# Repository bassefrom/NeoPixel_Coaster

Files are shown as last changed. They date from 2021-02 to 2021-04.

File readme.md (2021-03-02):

# NeoPixel Coaster
#
# The NeoPixel coaster is a battery driven coaster that light up using NeoPixels. 
# The NeoPixels are driven with an attiny85. 
# The colors of the NeoPixels are temperature dependent and the attiny85 is connected to a thermistor to calculate the appropriate RGB values for.
#
# Programming the attiny85:
#
# Program the Arduino Uno with Arduino as ISP example program
#
# Add support for attiny85 in Arduino IDE:
# Go to preferences in Arduino IDE.
# Add this line to Additional Boards Manager URLs: https://raw.githubusercontent.com/damellis/attiny/ide-1.6.x-boards-manager/package_damellis_attiny_index.json
# Under Tools, select ATtiny25/45/85 board
# Select ATtiny85 as Processor
# Select Internal 8MHz clock
#
# Connect Arduino pin 13 (SCK) to attiny85 pin 7
# Connect Arduino pin 12 (MISO) to attiny85 pin 6
# Connect Arduino pin 11 (MOSI) to attiny85 pin 5
# Connect Arduino pin 10 (RESET) to attiny85 pin 1
# Connect Arduino 5V to attiny85 pin 8
# Connect Arduino GND to attiny85 pin 4
#
# Burn Arduino bootloader to attiny85
# Program the attiny85 from Arduino IDE
#
#
# AVRDUDE programming to be implemented (not supported as of now):
# How to use avrdude for programming HEX-files to the attiny85 using Arduino Uno as ISP:
# Connect the attiny85 in the same way you connect it when programming using the Arduino IDE.
# attiny85 has name t85 in avrdude. Use the following line to verify the attiny85 is connected properly:
# avrdude -c avrisp -b 19200 -p t85 -P COMX -n
# Set 8MHz internal oscillator using these fuse bits: 0xE2 and 0xD9 with the followign line:
# avrdude -c avrisp -b 19200 -p t85 -P COMX -U lfuse:w:0xE2:m -U hfuse:w:0xD9:m
# Program the attiny85 using this line:
# avrdude -P COM1 -b 19200 -c avrisp -p t85 -u -U flash:w:"{HEX-file directory here}\file.hex":i
#
# It can be done using a single line as well:
# avrdude -P COM1 -b 19200 -c avrisp -p t85 -u -U efuse:w:0xFF:m -U lfuse:w:0xE2:m -U hfuse:w:0xD9:m -U flash:w:"{HEX-file directory here}\file.hex":i
#
# Example: avrdude -P COM1 -b 19200 -c avrisp -p t85 -u -U efuse:w:0xFF:m -U lfuse:w:0xE2:m -U hfuse:w:0xD9:m -U flash:w:"C:\Users\Basse\Documents\KiCad\NeoPixel_Coaster\Software\ATTiny85_NeoPixel\ATTiny85_NeoPixel.ino.hex":i

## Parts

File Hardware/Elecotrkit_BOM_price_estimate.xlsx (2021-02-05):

Id | Designator | Package | Quantity | Designation | Supplier and ref | Styckpris | 10st styckpris | Totalt pris | Totalt pris vid 5st | Enhetspris vid 10st
1 | BT1 | LiPo Battery 150mAh | 1 | Battery_Cell | https://www.electrokit.com/produkt/batteri-lipo-3-7v-400mah-2/ | 75 | 67.5 | 75 | 375 | 67.5
2 | J1 | USB_Mini-B_No_Holes | 1 | USB_B_Mini | https://www.electrokit.com/produkt/usb-mini-b-smd/ | 8.24 | 7.42 | 8.24 | 41.2 | 7.42
3 | C1,C2 | C_1206_3216Metric | 2 | 4.7u | https://www.electrokit.com/produkt/kondensator-1206-x7r-4-7uf-%c2%b110-16v/ | 4 | 4 | 8 | 40 | 8
4 | D1 | D_1206_3216Metric | 1 | LED | https://www.electrokit.com/produkt/led-orange-1206-100-mcd-klar/ | 2.45 | 2.21 | 2.45 | 12.25 | 2.21
5 | D2,D3,D4,D5 | WS2812_2020_SMD | 4 | WS2812B | https://www.electrokit.com/produkt/led-smd5050-rgb-adresserbar-sk6812/ | 5.5 | 4.68 | 22 | 110 | 18.72
6 | J2 | PinHeader_2x03_P1.27mm_Vertical_SMD | 1 | Conn_02x03_Odd_Even | https://www.electrokit.com/produkt/stiftlist-1-27mm-2x40p-smd/ or https://www.electrokit.com/produkt/hylslist-1-27mm-2x5p-smd/ | 1.5 | 1.5 | 1.5 | 7.5 | 1.5
7 | R1 | R_1206_3216Metric | 1 | 1k | https://www.electrokit.com/produkt/motstand-1kohm-0-25w-smd-1206/ | 0.35 | 0.35 | 0.35 | 1.75 | 0.35
8 | R2 | R_1206_3216Metric | 1 | 4.7k | https://www.electrokit.com/produkt/motstand-4-7kohm-0-25w-smd-1206/ | 0.35 | 0.35 | 0.35 | 1.75 | 0.35
9 | R3 | R_1206_3216Metric | 1 | 100k | https://www.electrokit.com/produkt/motstand-100kohm-0-25w-smd-1206/ | 0.35 | 0.35 | 0.35 | 1.75 | 0.35
10 | S1 | Skjutomkopplare 2-pol on-on-on pcb | 1 | EG1218 | https://www.electrokit.com/produkt/skjutomkopplare-mini-1-pol-on-on-smd/ | 9 | 8.1 | 9 | 45 | 8.1
11 | TH1 | R_1206_3216Metric | 1 | Thermistor | https://www.electrokit.com/produkt/ntc-100kohm-smd-1206/ | 4 | 3.6 | 4 | 20 | 3.6
12 | U1 | SOT-23-5 | 1 | MCP73831-2-OT | https://www.electrokit.com/produkt/mcp73831t-2aci-ot-sot-23-5-lipo-charger-4-2v/ | 6.63 | 5.97 | 6.63 | 33.15 | 5.97
13 | U2 | SOIJ-8_5.3x5.3mm_P1.27mm | 1 | ATtiny85-20SU | https://www.electrokit.com/produkt/attiny85-20su-so-8-8-bit-mcu-flash-8k/ | 29 | 26.1 | 29 | 145 | 26.1
 |  |  |  |  |  |  | Totalt | 166.87 | 834.35 | 150.17

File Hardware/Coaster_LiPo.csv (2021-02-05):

Reference | Value | Footprint | Datasheet | LCSC
U2 | ATtiny85-20SU | Package_SO:SOIJ-8_5.3x5.3mm_P1.27mm | http://ww1.microchip.com/downloads/en/DeviceDoc/atmel-2586-avr-8-bit-microcontroller-attiny25-attiny45-attiny85_datasheet.pdf | C89852
U1 | MCP73831-2-OT | Package_TO_SOT_SMD:SOT-23-5 | http://ww1.microchip.com/downloads/en/DeviceDoc/20001984g.pdf
C1 | 4.7u | Capacitor_SMD:C_1206_3216Metric | ~ | C29823
R2 | 4.7k | Resistor_SMD:R_1206_3216Metric | ~ | C17936
C2 | 4.7u | Capacitor_SMD:C_1206_3216Metric | ~ | C29823
BT1 | Battery_Cell | MyOwn:Batteri LiPo 3.7V 400mAh | ~
R1 | 1k | Resistor_SMD:R_1206_3216Metric | ~ | C4410
J1 | USB_B_Mini | Connector_USB:USB_Mini-B_Lumberg_2486_01_Horizontal | ~ | C91144
J2 | Conn_02x03_Odd_Even | Connector_PinHeader_1.27mm:PinHeader_2x03_P1.27mm_Vertical_SMD | ~
R3 | 100k | Resistor_SMD:R_1206_3216Metric | ~ | C17900
TH1 | Thermistor | Resistor_SMD:R_1206_3216Metric | ~
D1 | LED | LED_SMD:LED_1206_3216Metric | ~ | C93133
D2 | SK6812 | LED_SMD:LED_SK6812_PLCC4_5.0x5.0mm_P3.2mm | https://cdn-shop.adafruit.com/product-files/1138/SK6812+LED+datasheet+.pdf | C114586
D3 | SK6812 | LED_SMD:LED_SK6812_PLCC4_5.0x5.0mm_P3.2mm | https://cdn-shop.adafruit.com/product-files/1138/SK6812+LED+datasheet+.pdf | C114586
D4 | SK6812 | LED_SMD:LED_SK6812_PLCC4_5.0x5.0mm_P3.2mm | https://cdn-shop.adafruit.com/product-files/1138/SK6812+LED+datasheet+.pdf | C114586
D5 | SK6812 | LED_SMD:LED_SK6812_PLCC4_5.0x5.0mm_P3.2mm | https://cdn-shop.adafruit.com/product-files/1138/SK6812+LED+datasheet+.pdf | C114586
SW1 | SW_SPDT | Button_Switch_SMD:SW_SPDT_PCM12 | ~ | C136659

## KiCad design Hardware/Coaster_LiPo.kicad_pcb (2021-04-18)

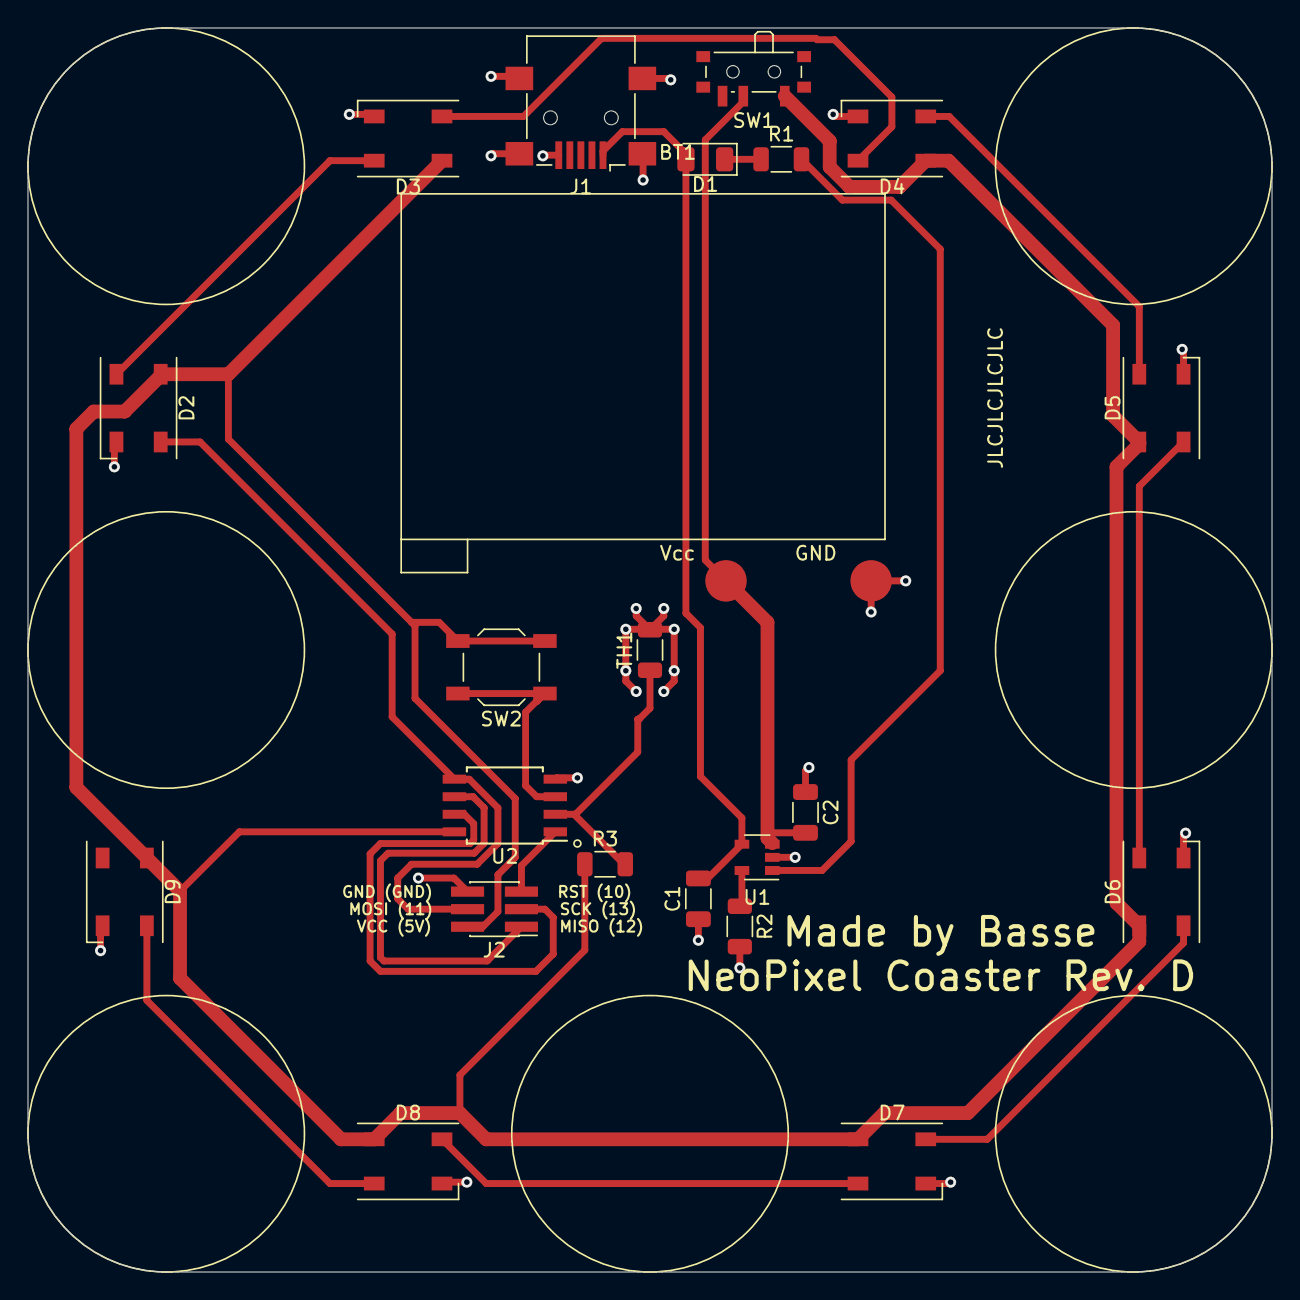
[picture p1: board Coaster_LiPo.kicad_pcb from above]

Board: 2 copper layers, 90.0 x 90.0 mm, 22 parts (0 on the bottom side), 20 nets.

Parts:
BT1: Battery_Cell; Batteri LiPo 3.7V 400mAh
C1, C2: 4.7u; C_1206_3216Metric
D1: LED; LED_1206_3216Metric
D2, D3, D4, D5, D6, D7, D8, D9: SK6812; LED_SK6812_PLCC4_5.0x5.0mm_P3.2mm
J1: USB_B_Mini; USB_Mini-B_Lumberg_2486_01_Horizontal
J2: Conn_02x03_Odd_Even; PinHeader_2x03_P1.27mm_Vertical_SMD
R1: 2.2k; R_1206_3216Metric
R2: 4.7k; R_1206_3216Metric
R3: 100k; R_1206_3216Metric
SW1: SW_SPDT; SW_SPDT_PCM12
SW2: SW_Push; SW_SPST_TL3342
TH1: Thermistor; R_1206_3216Metric
U1: MCP73831-2-OT; SOT-23-5
U2: ATtiny85-20SU; SOIJ-8_5.3x5.3mm_P1.27mm

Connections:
GND: BT1.2, C1.1, C2.1, D2.1, D3.1, D4.1, D5.1, D6.1, D7.1, D8.1, D9.1, J1.5, J1.6, J2.6, R2.2, TH1.2, U1.2, U2.4
MISO: J2.1, U2.6
MOSI: D2.2, J2.4, U2.5
unnamed: BT1.1, C2.2, SW1.2, U1.3
unnamed: C1.2, D1.2, J1.1, U1.4
unnamed: D1.1, R1.1
unnamed: D2.4, D3.2
unnamed: D3.4, D4.2
unnamed: D4.4, D5.2
unnamed: D5.4, D6.2
unnamed: D6.4, D7.2
unnamed: D7.4, D8.2
unnamed: D8.4, D9.2
unnamed: R1.2, U1.1
unnamed: R2.1, U1.5
unnamed: SW2.1, U2.3
Reset: J2.5, U2.1
SCK: J2.3, U2.7
SensOut: R3.2, TH1.1, U2.2
Vcc: D2.3, D3.3, D4.3, D5.3, D6.3, D7.3, D8.3, D9.3, J2.2, R3.1, SW1.1, SW2.2, U2.8

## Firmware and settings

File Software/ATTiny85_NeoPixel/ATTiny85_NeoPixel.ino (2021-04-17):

#include <Adafruit_NeoPixel.h>

#define PIN       0
#define sensPIN   PB3
#define buttonPIN PB4
#define NUMPIXELS 16

int delayval = 100;
long randNumer;
float Rref = 100000;
float const_A1 = 0.003354016;
float const_B1 = 0.0002460382;
float const_C1 = 0.000003405377;
float const_D1 = 0.000000103424;
float R, A, B, C, D, T;
int r = 0;
int g = 0;
int b = 0;

int chase = 1;

int fade = 1;
int fadeInt = 0;
int fadeClr = 1;

int buttonPushCounter = 0;   // counter for the number of button presses
int buttonState = 0;         // current state of the button
int lastButtonState = 0;     // previous state of the button

Adafruit_NeoPixel pixels = Adafruit_NeoPixel(NUMPIXELS, PIN, NEO_GRB + NEO_KHZ800);

void setup() {
  pixels.begin();
  pinMode(sensPIN,INPUT);
  pinMode(buttonPIN, INPUT);
  for(int i=0;i<NUMPIXELS;i++) {
    pixels.setPixelColor(i, pixels.Color(r,g,b));
  }
}

void loop() {
  buttonState = digitalRead(buttonPIN);
  if (buttonState != lastButtonState) {
    // if the state has changed, increment the counter
    if (buttonState == HIGH) {
      // if the current state is HIGH then the button went from off to on:
      buttonPushCounter++;
      if (buttonPushCounter > 6) {
        buttonPushCounter = 1;
      }
    }
    delay(50);
  }
  // save the current state as the last state, for next time through the loop
  lastButtonState = buttonState;

  switch (buttonPushCounter) {
    case 0:
    //Steinhart equation for T in Celsius from ADC value
    float X = analogRead(sensPIN);
    R = ((X/1023)*Rref/(1-(X/1023)));
    A = const_A1;
    B = const_B1 * log(R/Rref);
    C = const_C1 * pow(log(R/Rref), 2);
    D = const_D1 * pow(log(R/Rref), 3);
    T = 1/(A + B + C + D) - 273.15;
    r = 0;
    g = 0;
    b = 0;
  
    //Blue
    if (T < 25) {
      b = 25 - T;
      if (b < 0)
      {
        b = 0;
      }
    }
  
  
    //Green
    if (T < 20) {
      g = (T-10)*2.5;
    }
    if (T > 20) {
      g = 40 - (T-20)*2.5;
    }
    if (g < 0) {
      g = 0;
    }
  
    //Red
    if (T > 15) {
      r = T-15;
    }
    if (r > 25) {
      r = 25;
    }
  
    //Limit to 25
    if(b > 25) {
      b = 25;
    }
    if(r > 25) {
      r = 25;
    }
  
    //Update LEDs
    for(int i=0;i<8;i++) {
      pixels.setPixelColor(i, pixels.Color(r,g,b));
      pixels.show();
    }
    
  case 1: //Red
    for(int i=0;i<8;i++) {
      pixels.setPixelColor(i, pixels.Color(20,0,0));
      pixels.show();
    }
    
  case 2: //Green
    for(int i=0;i<8;i++) {
      pixels.setPixelColor(i, pixels.Color(0,20,0));
      pixels.show();
    }
    
  case 3: //Blue
    for(int i=0;i<8;i++) {
      pixels.setPixelColor(i, pixels.Color(0,0,20));
      pixels.show();
    }
    
  case 4: //White
    for(int i=0;i<8;i++) {
      pixels.setPixelColor(i, pixels.Color(20,20,20));
      pixels.show();
    }
    
  case 5: //Chase
    if (chase == 9) {
      chase = 1;
    }    
    for(int i=0;i<8;i++) {
      pixels.setPixelColor(i, pixels.Color(0,0,0));
      pixels.show();
    }
    pixels.setPixelColor(chase, pixels.Color(20,20,20));
    pixels.show();
    chase++;
    delay(delayval); //Twice delayval for slower chase
    
  case 6:  //RGB Fade
    if (fadeInt == 20) {
      fade = 0;
    }
    if (fadeInt == 0) {
      fadeClr++;
    }
    if (fadeClr > 3) {
      fadeClr = 1;
    }
    switch(fadeClr) {
      case 1:
      for(int i=0;i<8;i++) {
        pixels.setPixelColor(i, pixels.Color(fadeInt,0,0));
        pixels.show();
      }
      case 2:
      for(int i=0;i<8;i++) {
        pixels.setPixelColor(i, pixels.Color(0,fadeInt,0));
        pixels.show();
      }
      case 3:
      for(int i=0;i<8;i++) {
        pixels.setPixelColor(i, pixels.Color(0,0,fadeInt));
        pixels.show();
      }
      if (fade == 1) {
        fadeInt++;
      }
      else {
        fadeInt--;
      }
    }
    
  }

  delay(delayval);
}

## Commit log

2021-02-05 Changed LEDs to 5050 and switch to standard SPDT
    [Coaster.kicad_pcb, Coaster.sch]
2021-02-05 Replaced CR2032 batteries with LiPo. Boost converted changed to charge IC. Silk screen for rubber feet added
    [Coaster.csv, Coaster.kicad_pcb, Coaster.sch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]
2021-02-05 Added Attiny85 Arduino code
2021-02-05 Renamed code file and capped LED intensity to 25 for each color
2021-02-05 DigiKey components added
    [DigiKey_component_purchase.xlsx]
2021-03-02 Updated Readme and minor tweaks after first prototype build
    [Coaster_LiPo.sch]
2021-03-06 Added graphics, rearranged components, added 4 more neopixels
    [Coaster_LiPo.kicad_pcb, Coaster_LiPo.sch]
2021-04-17 Added push button to cycle through LED modes
    [Coaster_LiPo.kicad_pcb, Coaster_LiPo.sch]
2021-04-18 Moved a via and limited logo
    [Coaster_LiPo-B_Cu.gbl, Coaster_LiPo-B_Mask.gbs, Coaster_LiPo-B_Paste.gbp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]
2021-04-18 Removed old gerbers
    [Coaster_LiPo-B_Cu.gbl, Coaster_LiPo-B_Mask.gbs, Coaster_LiPo-B_Paste.gbp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]
